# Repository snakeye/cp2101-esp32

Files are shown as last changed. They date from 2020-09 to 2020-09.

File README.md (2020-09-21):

# Universal programmer for ESP8266/ESP32

The repository contains Eagle CAD project for building programming device for ESP8266/ESP32 microcontrollers.

* Support for popular ESP-01 and ESP-12 modules
* Boot/Reset circuitry for automatic flashing
* Separate +3.3V power line

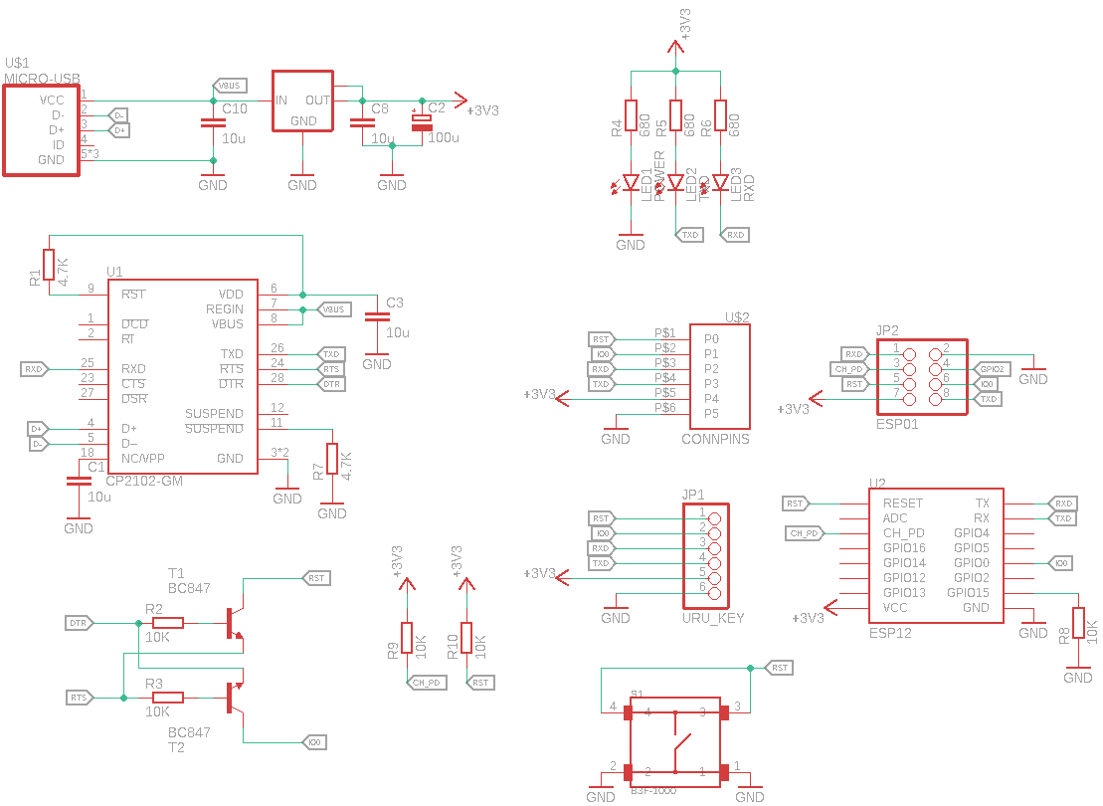
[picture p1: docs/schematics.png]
Docs


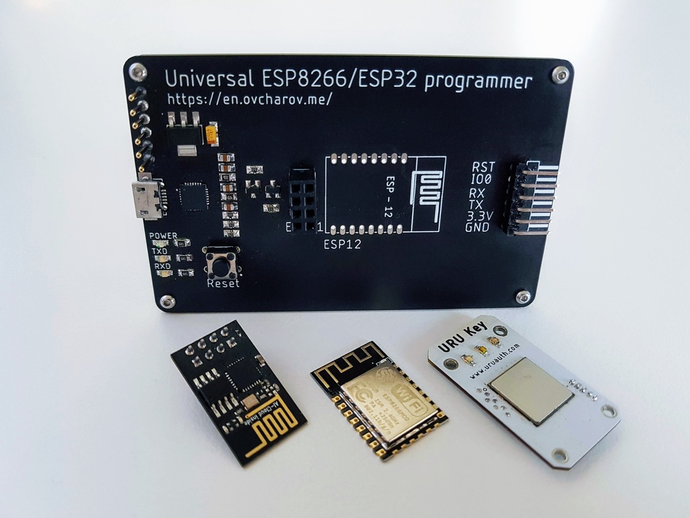
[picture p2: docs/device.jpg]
Completed device


More info in my blog [https://en.ovcharov.me/2020/09/19/universal-esp8266-esp32-programmer/](https://en.ovcharov.me/2020/09/19/universal-esp8266-esp32-programmer/).

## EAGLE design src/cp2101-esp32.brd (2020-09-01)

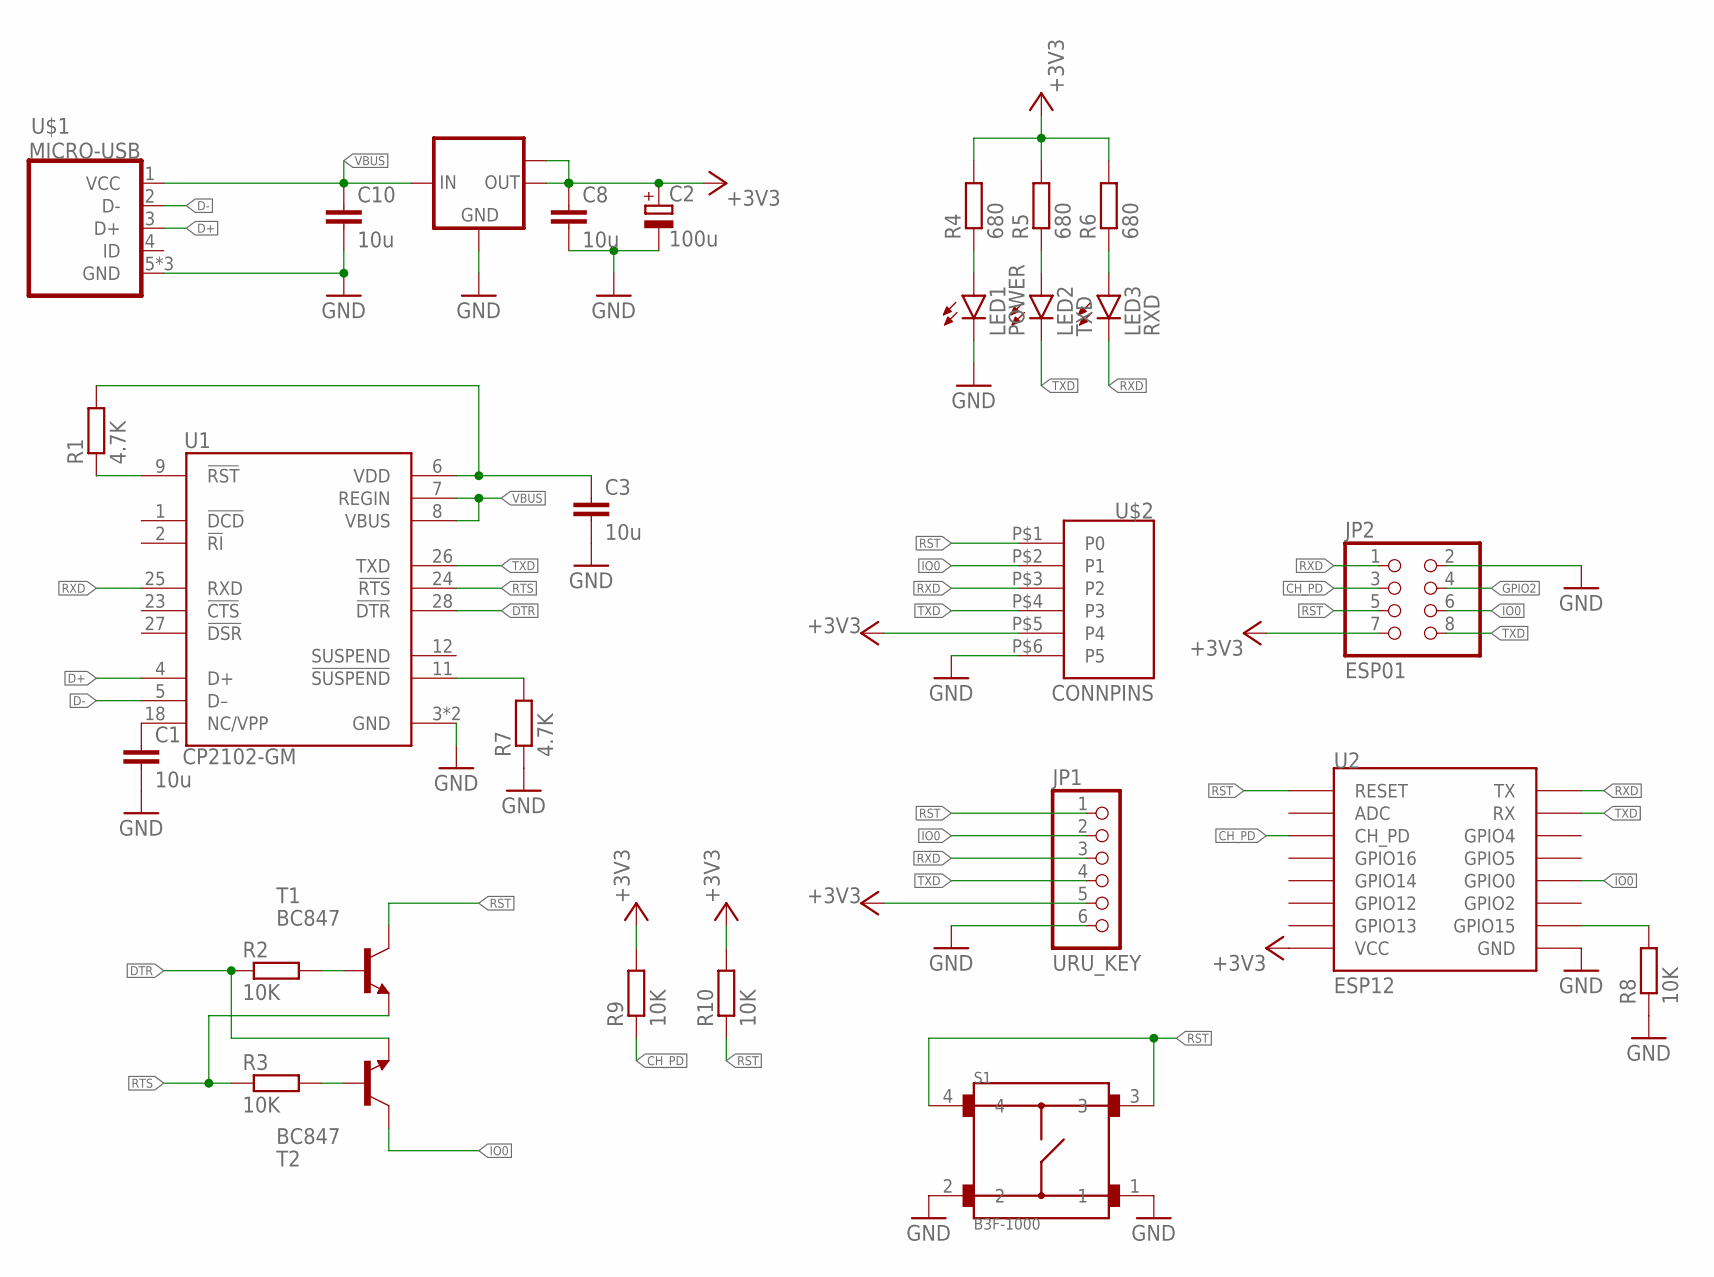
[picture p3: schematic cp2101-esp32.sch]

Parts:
C1, C3, C8, C10: 10u; C0805
C2: 100u; A/3216-18R
IC1: LM1117MPX-3.3; SOT223
JP1: URU_KEY; 1X06/90
JP2: ESP01; 2X04
LED1: POWER; CHIP-LED0805
LED2: TXD; CHIP-LED0805
LED3: RXD; CHIP-LED0805
R1, R7: 4.7K; R0805
R2, R3, R8, R9, R10: 10K; R0805
R4, R5, R6: 680; R0805
S1: B3F-1000; SW_B3F-1000
T1, T2: BC847; SOT23
U1: CP2102-GM; QFN50P500X500X100-29N
U2: ESP12
U$1: MICRO-USB
U$2: CONNPINS; PINS

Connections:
+3V3: C2.+, C8.1, IC1.2 (OUT), IC1.TAB (OUT1), JP1.5, JP2.7, R4.2, R5.2, R6.2, R9.2, R10.2, U2.VCC, U$2.P$5 (P4)
CH_PD: JP2.3, R9.1, U2.CH_PD
D+: U1.4 (D+), U$1.3 (D+)
D-: U1.5 (D–), U$1.2 (D-)
DTR: R2.1, T2.2 (E), U1.28 (!DTR)
GND: C1.2, C2.-, C3.2, C8.2, C10.2, IC1.1 (GND), JP1.6, JP2.2, LED1.C, R7.1, R8.1, S1.1, S1.2, U1.3 (GND), U1.29 (GND), U2.GND, U$1.5 (GND), U$1.GND1 (GND), U$1.GND2 (GND), U$2.P$6 (P5)
GPIO2: JP2.4
IO0: JP1.2, JP2.6, T2.3 (C), U2.GPIO0, U$2.P$2 (P1)
unnamed: C1.1, U1.18 (NC/VPP)
unnamed: C3.1, R1.2, U1.6 (VDD)
unnamed: R7.2, U1.11 (!SUSPEND)
unnamed: R8.2, U2.GPIO15
unnamed: LED1.A, R4.1
unnamed: R1.1, U1.9 (!RST)
unnamed: R2.2, T1.1 (B)
unnamed: R3.2, T2.1 (B)
unnamed: LED2.A, R5.1
unnamed: LED3.A, R6.1
RST: JP1.1, JP2.5, R10.1, S1.3, S1.4, T1.3 (C), U2.RESET, U$2.P$1 (P0)
RTS: R3.1, T1.2 (E), U1.24 (!RTS)
RXD: JP1.3, JP2.1, LED3.C, U1.25 (RXD), U2.TX, U$2.P$3 (P2)
TXD: JP1.4, JP2.8, LED2.C, U1.26 (TXD), U2.RX, U$2.P$4 (P3)
VBUS: C10.1, IC1.3 (IN), U1.7 (REGIN), U1.8 (VBUS), U$1.1 (VCC)

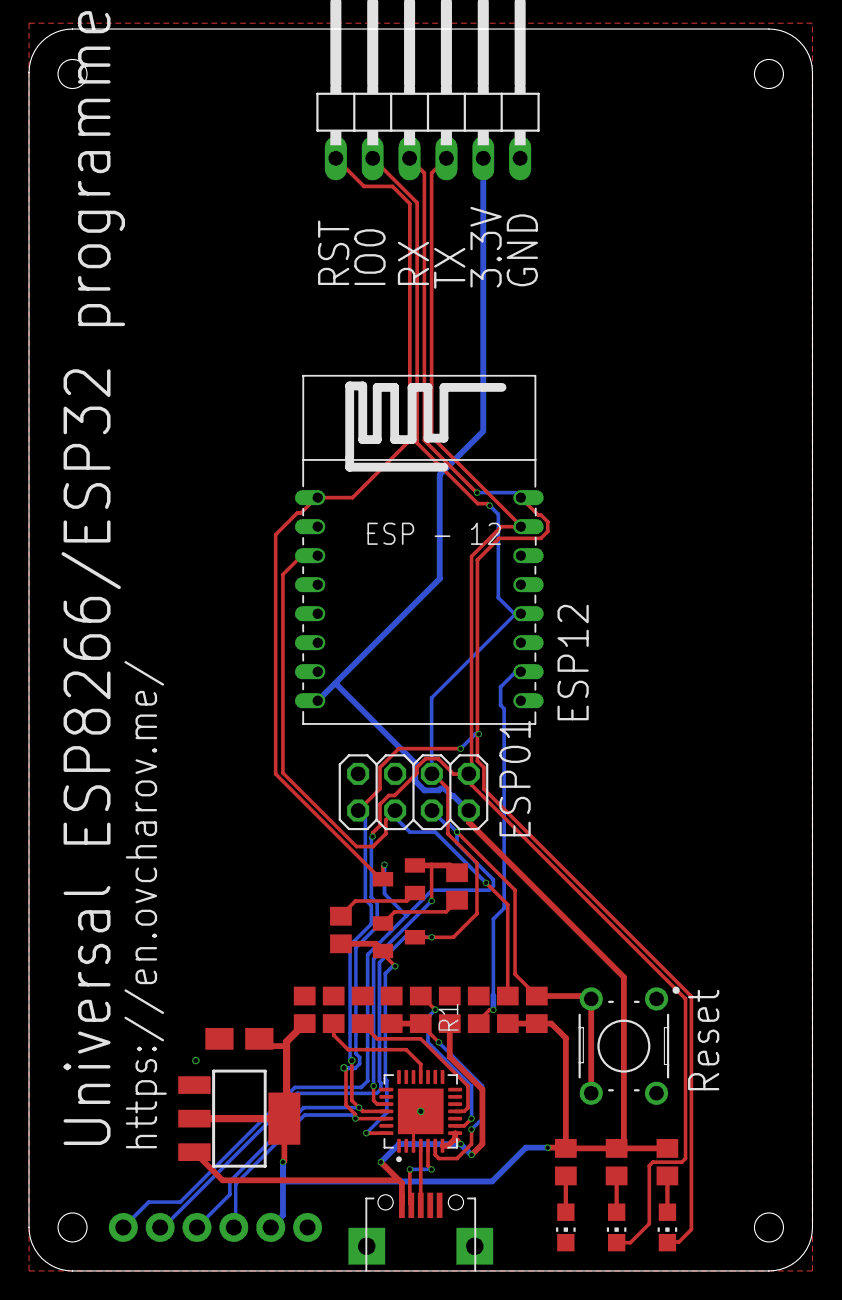
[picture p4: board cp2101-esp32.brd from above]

Board: 2 copper layers, 54.0 x 85.6 mm, 28 parts (0 on the bottom side), 22 nets.

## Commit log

2020-08-31 Added eagle files
    [cp2101-esp32.brd, cp2101-esp32.sch]
2020-09-01 Added connectors
    [cp2101-esp32.brd, cp2101-esp32.sch]
